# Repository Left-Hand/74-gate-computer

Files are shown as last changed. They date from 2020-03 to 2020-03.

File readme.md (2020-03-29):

# 本文档用于帮助您快速理解本微型计算机的构成
## 特征及功能

* 核心频率期待值为16Mhz，保守预估为8Mhz（暂未测试，待实体机研制出来后测试）
* 绝大多数指令为1T，不使用微指令 *部分另外说明
* 使用冯·诺伊曼架构（最初是使用哈佛架构）
* 使用74门作为本计算机的核心组件，并且不使用其他可编程组件（单片机，FPGA，CPLD等）

* 支持VGA显卡，分辨率为256*240。为4片is62c256分为两组乒乓工作，能够硬件上下回滚，自动修改地址为下一个字符
* 包含2个16位定时器，可屏蔽计时器信号，产生7位权中断
* PC(program counter)程序计数器为24位，能够寻址宽度为2M，前一半分配给AT28系列或是W27C系列芯片作为引导程序，后半部分为单片8Mbit的
sram，用于储存数据和运行程序
* 支持硬件ALU加速乘除操作，需要配置ALU相关寄存器，核心运算部分在16个时钟内完成（不包括配置寄存器及载入读出）

---
## 动机及声明

本人在16年左右看了commdore64的测评，认为非常新奇，于是整天幻想做一个自己的计算机，于17年开始构思（但是当时想的都是一些怪点子，比如用FR储存器作为Vram，使用摇摇棒作为显示屏等），直到下半年到18年出才正式开始用74构造切实可行的电路，并且陆续发布相关文章（黑历史bushi），最后在digital软件下逐步仿真出我想要的电路

主页：https://space.bilibili.com/28690875

专栏：https://www.kechuang.org/t/83193

本项目为开源项目，可能会出相关套件，请勿盗用。
由于我是一名在校高一年级高中生，因学业原因可能进度推展缓慢

---
## 文件

主目录下有一个POB.dig文件，为项目的主文件。使用hneemann的digtial作为仿真的ide（需要安装java），可以在 https://github.com/hneemann/Digital 中找到

作者的提供的库并不适合本项目，我将example/lib下的文件做了替换，解压主目录下的lib.zip文件并替换，方可使用本项目

ES目录下为旧的模块测试用文件，曾有模块化的打算，但是因无法看到底层电路的状态而放弃这一方案

---
## 原理
本计算机与其他微机不同，没有微指，例如C语言中的

```
A = B;
```
在大部分微机中，这条指令包括数个微指令：

```
1. 使B寄存器输出总线使能
2. 控制A载入总线中的数据
3. B寄存器输出结束
4. 检查其他操作...
```

但是，在本机中，绝大多数指令（不涉及修改返回PC值）为1T指令，即一条指令只花费一个周期

此机中，花费两个指令：
```
1. 切换为B寄存器输出到总线
2. 向A寄存器发出载入脉冲
```

再比如一个稍微复杂的（A，B分别为ALU内部的两个寄存器）：

```
C = A + B;
```
执行操作如下（对应一个周期）：

```
1. 切换为立即数寄存器输出到总线
2. 输出加法的ALU控制码（使用74181作为ALU，有多位控制译码线，无法简单操作）
3. ALU载入控制码
4. 切换为ALU输出到总线
5. C寄存器载入总线中的内容
```

故而，在本机中大部分操作使用译码器实现。有两种选通通道，P以及O，均为6位，各自可选通64个不同的脉冲，其区别在于
* P中只会在CLK主时钟发出脉冲时发出脉冲
* O会一直保存为上次载入之后的内容，且持续输出

这样，我们需要操作诸如A = B的操作，先修改O的指针以使B输出，再是P指向A载入的脉冲并放出脉冲，即可完成这样的操作

---
## 指令结构

单个指令为8bit，如果后缀了操作数，那么则为16bit单个操作的字节这样分配

| 7 | 6 | 5 | 4 | 3 | 2 | 1 | 0 |
| -- | -- | -- | -- | -- | -- | -- | -- |
|下一位数据有无| 是否为O指令 | P5/O5 | P4/O4 | P3/O3 | P2/O2 |P1/O1 | P0/O0

需要说明的是，数据必须在指令之前给出，这使我们的汇编码写起来似乎有点反人类，但是这样做也是合情合理的

例如，A寄存器载入的指令为001(前包含一位0表示8进制)
下面是一段实现"A = 0x19"的汇编代码(此处为方便没有配置A寄存器,实际需要):

```
BUSO 0x19
ACP
```

这里我们的BUSO指使总线上的立即数寄存器输出(为000（八进制中的0，八进制不使用如0x，0b的前缀，而是0）)，它的出现同时为了引入0x19这样一个操作数，我们把它编译出来
```
| 1 | 1 | 0 | 0 | 0 | 0 | 0 | 0 | //BUSO指令，下接操作数
| 0 | 0 | 0 | 1 | 0 | 0 | 1 | 1 | //操作数0x19
| 0 | 0 | 0 | 0 | 0 | 0 | 0 | 1 | //A寄存器载入控制符
```
这样，我们的A寄存器就可以载入0x19这样的数字了其背后的逻辑控制稍显复杂，我们不做讨论

---

## 操作符
下面列出所有操作符（空为未定）

P操作符:

|序列号|汇编助记符|说明|
| --- | --- | --- |
|__000000__|NON|不做任何操作|
|000001|ACP|向A寄存器输出脉冲，视当前操作状态而定|
|000010|AMR|A寄存器清零|
|000011|STL|使A寄存器操作状态为左移|
|000100|STR|使A寄存器操作状态为右移|
|000101|LDM|使A寄存器操作状态为载入|
|000110|BLLD|使BL寄存器载入|
|000111|BHLD|使BH寄存器载入|
|__001000__|AILD|使A寄存器右侧移位寄存器载入|
|001001|MLD|使M寄存器载入（硬件乘法加速相关）|
|001010|STC|使ALU进位输入清零|
|001011|CLC|使ALU进位输入制位|
|001100|REC|使ALU进位输入为进位输出|
|001101|NF|第一次移位操作禁止（硬件除法加速相关）|
|001110|CAI|清除A寄存器右移移入数据（硬件乘法加速相关）|
|001111|ACLD|ALU控制符载入|
|__010000__|PCLLD|程序计数器最低字节预载入|
|010001|PCMLD|程序计数器中字节预载入|
|010010|PCHLD|程序计数器高字节预载入|
|010011|FBK|强制备份当前程序计数器至备份0|
|010100|RD|读写储存器操作为读|
|010101|WT|读写储存器操作为写|
|010110|RET|返回备份0的程序地址|
|010111|GED|程序计数器备份至备份1，读写预载入的地址数据并返回|
|__011000__|JMP|无条件跳转预载入的地址|
|011001|HLT|宕机|
|011010|JC|在ALU状态寄存器输出情况下，有进位输出跳转|
|011011|JNC|在ALU状态寄存器输出情况下，无进位输出跳转|
|011100|JZ|在ALU状态寄存器输出情况下，ALU得数为0时跳转|
|011101|JNZ|在ALU状态寄存器输出情况下，ALU得数不为0时跳转|
|011110|JV|在ALU状态寄存器输出情况下，ALU得数溢出跳转|
|011111|JNV|在ALU状态寄存器输出情况下，ALU得数未溢出跳转|
|__100000__|T0LLD|定时器T0低位载入|
|100001|T0HLD|定时器T0高位载入|
|100010|T1LLD|定时器T1低位载入|
|100011|T1HLD|定时器T1高位载入|
|100100|CTC|设置定时器中断许可|
|100101|CTI|设置中断许可|
|100110|INT3|强制中断3|
|100111|INT1|强制中断1|
|__101000__|IO0|IO0载入|
|101001|IO1|IO1载入|
|101010|CLD|C寄存器载入|
|101011|DLD|D寄存器载入|
|101100|IOLD|IO口控制数据流寄存器载入 |
|101101|||
|101110|||
|101111|||
|__110000__|||
|110001|||
|110010|||
|110011|||
|110100|||
|110101|||
|110110|||
|110111|||
|__111000__|SAM|设置A组屏幕输出|
|111001|IVS|切换为另一组屏幕输出|
|111010|WVGA|写VGA数据|
|111011|YP|设置Y偏转|
|111100|LXB|准备载入X地址|
|111101|LX|X地址载入|
|111110|LYB|准备载入Y地址|
|111111|LY|Y地址载入|

O操作符:

|序列号|汇编助记符|说明|
| --- | --- | --- |
|__000000__|BUSO|总线立即数寄存器输出|
|000001|UO|ALU输出|
|000010|DO|除法寄存器输出|
|000011|AOO|A寄存器右侧输出寄存器输出|
|000100|ACO|ALU状态输出|
|000101|PCLO|程序计数器低位预输入输出|
|000110|PCMO|程序计数器中位预输入输出|
|000111|PCHO|程序计数器高位预输入输出|
|__001000__|RDTO|读取的储存器数据输出|
|001001|INTO|中断信号编码输出|
|001010|CRO|C寄存器输出|
|001011|DRO|D寄存器输出|
|001100|IO0O|IO0输出|
|001101|IO1O|IO1输出|

---
## 汇编器及烧录

主目录下的asm.py文件，使用python写了一个简易的汇编器，用于将类似汇编代码更为底层的代码转换为机器码，省去人力编写的痛苦，写完之后将文档（txt格式）的地址修改进python代码中，在命令行的输出中可以找到编译出的机器码，将这段文本修改进入POB.dig文件下（实质上是xml文件），在ROM的data属性中替换为该段文本

---
## 各个寄存器逻辑详解

待补充

---
## 其他

koishi赛高

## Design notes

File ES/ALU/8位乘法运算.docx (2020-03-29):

8位乘法运算

使用8位CPU运行，纯运行16周期，配合16Mhz晶振可以达到1Mhz的运算效率

测试:

145×222=32190（1001 0001×1101 1110=0111 1101 1011 1110）

0000 0000 0111 1110 1110

0000 0000 1001 0001

--------------------- (0) -------------------- (4)

0000 0000 1 0000 1111 1110

0000 0000 0 1000 0111 1111 0

1001 0001 0000 0000

--------------------- (1) -------------------- (5)

1001 0001 0 1000 0111 1111 0

0100 1000 10 0100 0011 1111 10

1001 0001 1001 0001

--------------------- (2) --------------------- (6)

1101 1001 10 1101 0100 1111 10

0110 1100 110 0110 1010 0111 110

1001 0001 1001 0001

--------------------- (3) --------------------- (7)

1111 1101 110 1111 1011 0111 110

0111 1110 1110 0111 1101 1011 1110

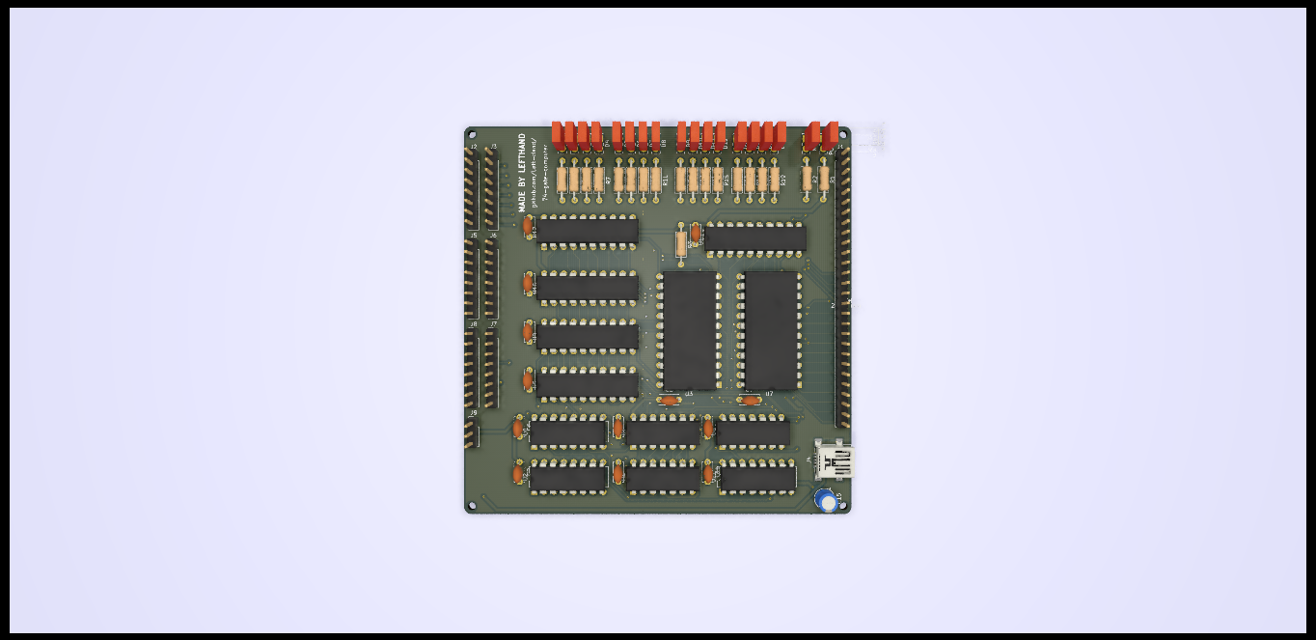
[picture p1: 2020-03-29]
kicad/ALU1/ALU1.png

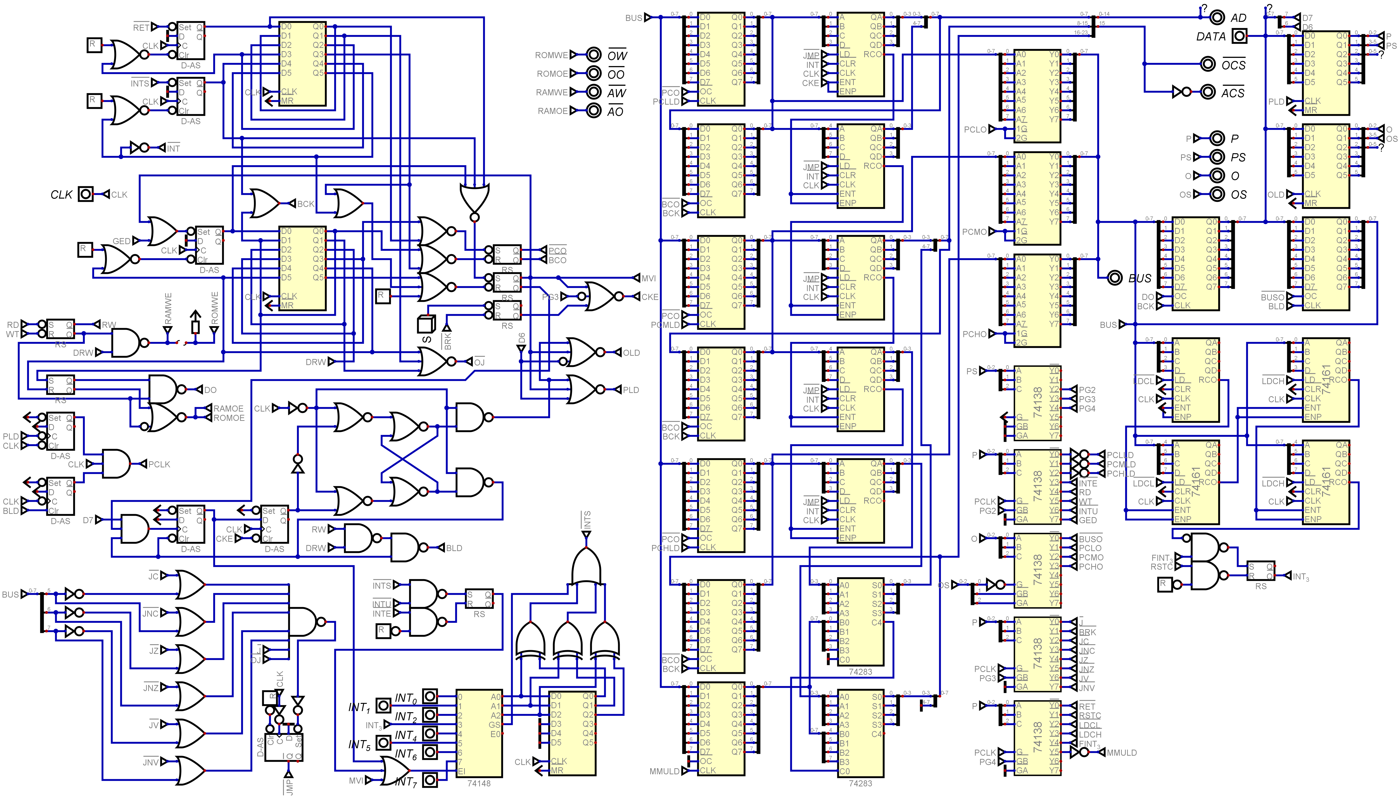
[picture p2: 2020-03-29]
ES/MEM/MEMORY_moudle.png

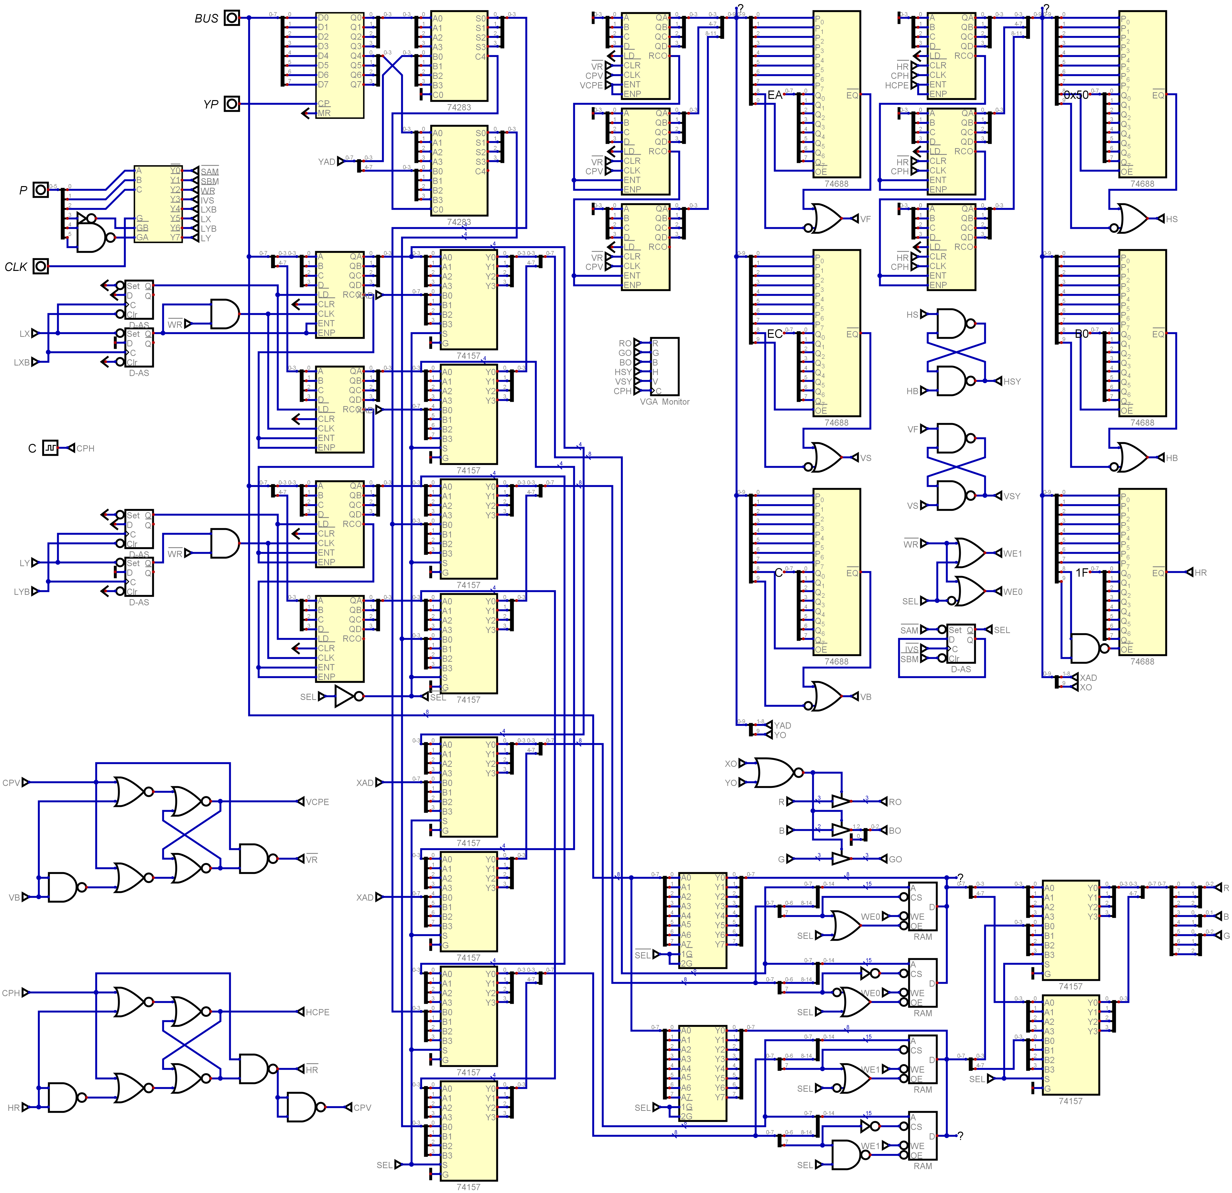
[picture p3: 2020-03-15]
ES/VGA/vga.png

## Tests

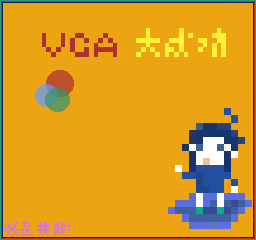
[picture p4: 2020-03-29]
ES/VGA/testimage.png

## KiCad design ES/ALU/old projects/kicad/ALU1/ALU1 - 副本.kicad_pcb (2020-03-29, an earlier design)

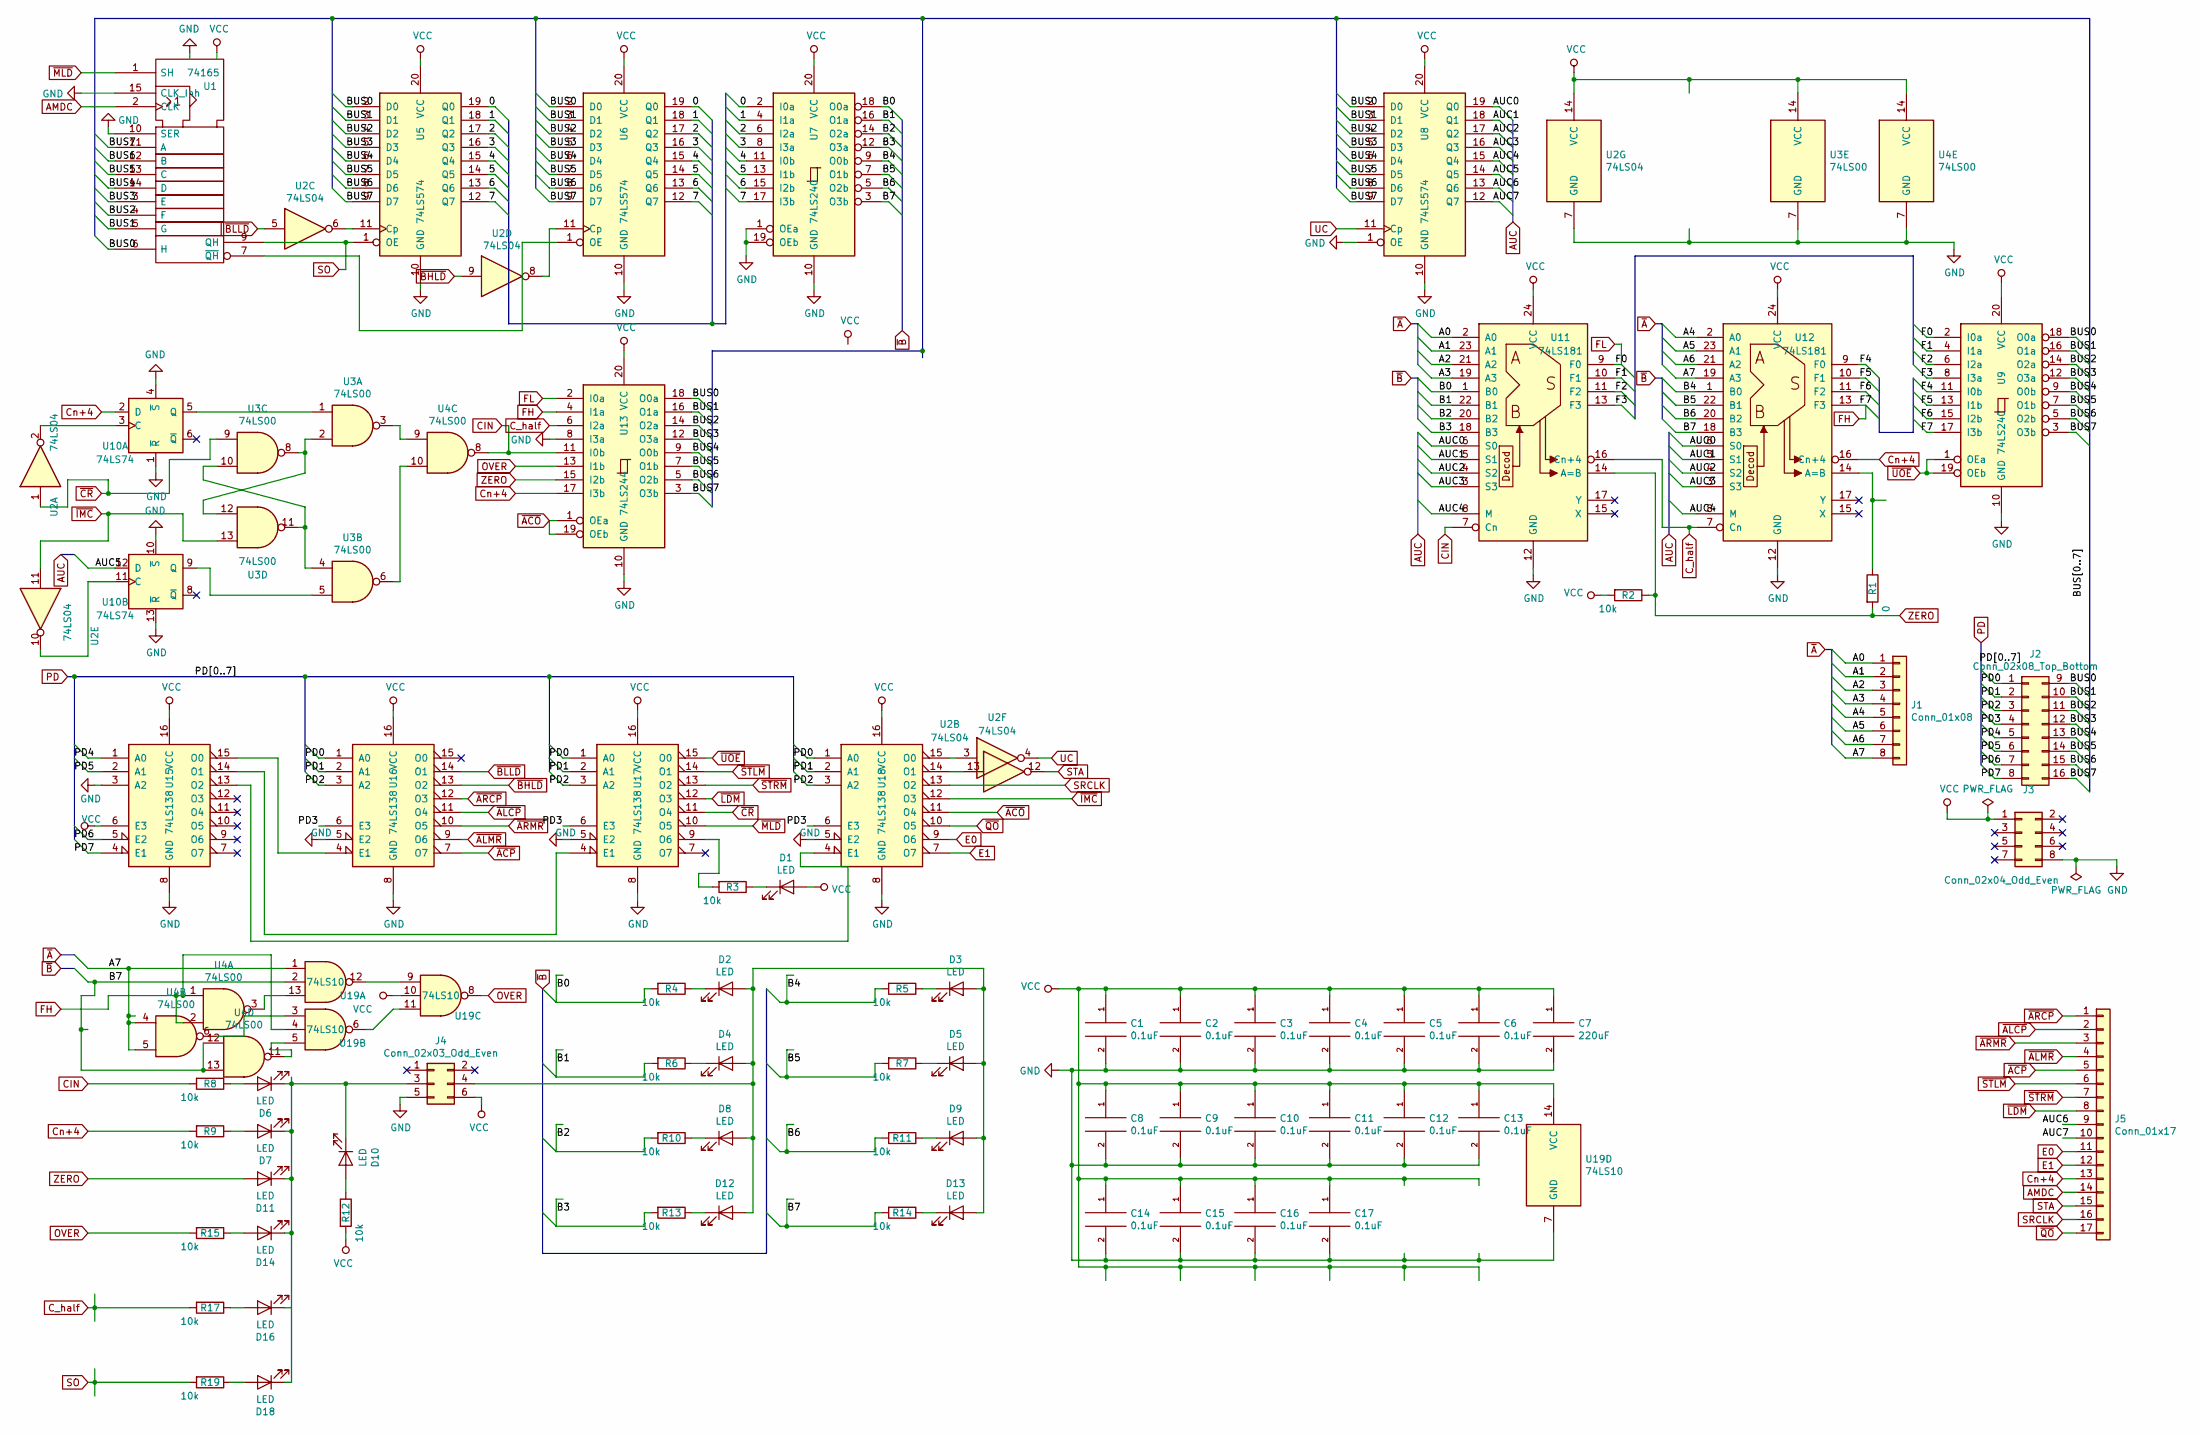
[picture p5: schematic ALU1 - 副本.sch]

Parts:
C1, C2, C3, C4, C5, C6, C8, C9, C10, C11, C12, C13, C14, C15, C16, C17: 0.1uF; C_Disc_D5.0mm_W2.5mm_P5.00mm
C7: 220uF; C_Radial_D6.3mm_H7.0mm_P2.50mm
D1, D2, D3, D4, D5, D6, D7, D8, D9, D10, D11, D12, D13, D14, D16, D18: LED; LED_Rectangular_W5.0mm_H2.0mm
J1: Conn_01x08; PinHeader_1x08_P2.54mm_Vertical
J2: Conn_02x08_Top_Bottom; PinHeader_2x08_P2.54mm_Horizontal
J3: Conn_02x04_Odd_Even; PinHeader_2x04_P2.54mm_Horizontal
J4: Conn_02x03_Odd_Even; PinHeader_2x03_P2.54mm_Vertical
J5: Conn_01x17; PinHeader_1x17_P2.54mm_Vertical
R1: 0; R_0805_2012Metric
R2, R3, R4, R5, R6, R7, R8, R9, R10, R11, R12, R13, R14, R15, R17, R19: 10k; R_0805_2012Metric
U1: 74165; DIP-16_W7.62mm
U2: 74LS04; DIP-14_W7.62mm
U3, U4: 74LS00; DIP-14_W7.62mm
U5, U6, U8: 74LS574; DIP-20_W7.62mm
U7, U9: 74LS240; DIP-20_W7.62mm
U10: 74LS74; DIP-14_W7.62mm
U11, U12: 74LS181; DIP-24_W15.24mm
U13: 74LS244; DIP-20_W7.62mm
U15, U16, U17, U18: 74LS138; DIP-16_W7.62mm
U19: 74LS10; DIP-14_W7.62mm

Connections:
/0: U5.19 (Q0), U6.19 (Q0), U7.2 (I0a)
/1: U5.18 (Q1), U6.18 (Q1), U7.4 (I1a)
/2: U5.17 (Q2), U6.17 (Q2), U7.6 (I2a)
/3: U5.16 (Q3), U6.16 (Q3), U7.8 (I3a)
/4: U5.15 (Q4), U6.15 (Q4), U7.11 (I0b)
/5: U5.14 (Q5), U6.14 (Q5), U7.13 (I1b)
/6: U5.13 (Q6), U6.13 (Q6), U7.15 (I2b)
/7: U5.12 (Q7), U6.12 (Q7), U7.17 (I3b)
/A0: J1.1, U11.2 (A0)
/A1: J1.2, U11.23 (A1)
/A2: J1.3, U11.21 (A2)
/A3: J1.4, U11.19 (A3)
/A4: J1.5, U12.2 (A0)
/A5: J1.6, U12.23 (A1)
/A6: J1.7, U12.21 (A2)
/A7: J1.8, U4.4, U4.5, U12.19 (A3), U19.1
/AUC0: U8.19 (Q0), U11.6 (S0), U12.6 (S0)
/AUC1: U8.18 (Q1), U11.5 (S1), U12.5 (S1)
/AUC2: U8.17 (Q2), U11.4 (S2), U12.4 (S2)
/AUC3: U8.16 (Q3), U11.3 (S3), U12.3 (S3)
/AUC4: U8.15 (Q4), U11.8 (M), U12.8 (M)
/AUC5: U8.14 (Q5), U10.12 (D)
/AUC6: J5.9, U8.13 (Q6)
/AUC7: J5.10, U8.12 (Q7)
/B0: R4.2, U7.18 (O0a), U11.1 (B0)
/B1: R6.2, U7.16 (O1a), U11.22 (B1)
/B2: R10.2, U7.14 (O2a), U11.20 (B2)
/B3: R13.2, U7.12 (O3a), U11.18 (B3)
/B4: R5.2, U7.9 (O0b), U12.1 (B0)
/B5: R7.2, U7.7 (O1b), U12.22 (B1)
/B6: R11.2, U7.5 (O2b), U12.20 (B2)
/B7: R14.2, U4.12, U4.13, U7.3 (O3b), U12.18 (B3), U19.2
/BUS0: J2.9, U1.6 (H), U5.2 (D0), U6.2 (D0), U8.2 (D0), U9.18 (O0a), U13.18 (O0a)
/BUS1: J2.10, U1.5 (G), U5.3 (D1), U6.3 (D1), U8.3 (D1), U9.16 (O1a), U13.16 (O1a)
/BUS2: J2.11, U1.4 (F), U5.4 (D2), U6.4 (D2), U8.4 (D2), U9.14 (O2a), U13.14 (O2a)
/BUS3: J2.12, U1.3 (E), U5.5 (D3), U6.5 (D3), U8.5 (D3), U9.12 (O3a), U13.12 (O3a)
/BUS4: J2.13, U1.14 (D), U5.6 (D4), U6.6 (D4), U8.6 (D4), U9.9 (O0b), U13.9 (O0b)
/BUS5: J2.14, U1.13 (C), U5.7 (D5), U6.7 (D5), U8.7 (D5), U9.7 (O1b), U13.7 (O1b)
/BUS6: J2.15, U1.12 (B), U5.8 (D6), U6.8 (D6), U8.8 (D6), U9.5 (O2b), U13.5 (O2b)
/BUS7: J2.16, U1.11 (A), U5.9 (D7), U6.9 (D7), U8.9 (D7), U9.3 (O3b), U13.3 (O3b)
/F1: U9.4 (I1a), U11.10 (F1)
/F2: U9.6 (I2a), U11.11 (F2)
/F3: U9.8 (I3a), U11.13 (F3)
/F4: U9.11 (I0b), U12.9 (F0)
/F5: U9.13 (I1b), U12.10 (F1)
/F6: U9.15 (I2b), U12.11 (F2)
/PD0: J2.1, U16.1 (A0), U17.1 (A0), U18.1 (A0)
/PD1: J2.2, U16.2 (A1), U17.2 (A1), U18.2 (A1)
/PD2: J2.3, U16.3 (A2), U17.3 (A2), U18.3 (A2)
/PD3: J2.4, U16.6 (E3), U17.6 (E3), U18.6 (E3)
/PD4: J2.5, U15.1 (A0)
/PD5: J2.6, U15.2 (A1)
/PD6: J2.7, U15.5 (E2)
/PD7: J2.8, U15.4 (E1)
AMDC: J5.14, U1.2 (CLK)
CIN: R8.2, U4.8, U11.7 (Cn), U13.11 (I0b)
C_half: R17.2, U11.16 (Cn+4), U12.7 (Cn), U13.6 (I2a)
Cn+4: J5.13, R9.2, U10.2 (D), U12.16 (Cn+4), U13.17 (I3b)
E0: J5.11, U18.9 (O6)
E1: J5.12, U18.7 (O7)
FH: U4.1, U4.2, U9.17 (I3b), U12.13 (F3), U13.4 (I1a), U19.4
FL: U9.2 (I0a), U11.9 (F0), U13.2 (I0a)
GND: C1.2, C2.2, C3.2, C4.2, C5.2, C6.2, C7.2, C8.2, C9.2, C10.2, C11.2, C12.2, C13.2, C14.2, C15.2, C16.2, C17.2, J3.8, J4.5, U1.8 (GND), U1.10 (SER), U1.15 (CLK_Inh), U2.7 (GND), U3.7 (GND), U4.7 (GND), U5.10 (GND), U6.10 (GND), U7.1 (OEa), U7.10 (GND), U7.19 (OEb), U8.1 (OE), U8.10 (GND), U9.10 (GND), U10.1 (~R), U10.4 (~S), U10.10 (~S), U10.13 (~R), U11.12 (GND), U12.12 (GND), U13.8 (I3a), U13.10 (GND), U15.3 (A2), U15.8 (GND), U16.5 (E2), U16.8 (GND), U17.5 (E2), U17.8 (GND), U18.5 (E2), U18.8 (GND), U19.7 (GND); also elsewhere on the board
unnamed: D1.1 (K), R3.1
unnamed: D2.1 (K), R4.1
unnamed: D3.1 (K), R5.1
unnamed: D4.1 (K), R6.1
unnamed: D5.1 (K), R7.1
unnamed: D6.2 (A), R8.1
unnamed: D7.2 (A), R9.1
unnamed: D8.1 (K), R10.1
unnamed: D9.1 (K), R11.1
unnamed: D6.1 (K), D7.1 (K), D10.1 (K), D11.1 (K), D14.1 (K), D16.1 (K), D18.1 (K), J4.3
unnamed: D10.2 (A), R12.1
unnamed: D12.1 (K), R13.1
unnamed: D2.2 (A), D3.2 (A), D4.2 (A), D5.2 (A), D8.2 (A), D9.2 (A), D12.2 (A), D13.2 (A), J4.4
unnamed: D13.1 (K), R14.1
unnamed: D14.2 (A), R15.1
unnamed: D16.2 (A), R17.1
unnamed: D18.2 (A), R19.1
unnamed: R1.1, U12.14 (A=B)
unnamed: R3.2, U17.9 (O6)
unnamed: U1.7 (~QH), U6.1 (OE)
unnamed: U2.6, U5.11 (Cp)
unnamed: U2.8, U6.11 (Cp)
unnamed: U3.3, U4.9
unnamed: U3.6, U4.10
unnamed: U3.4, U3.10, U3.11
unnamed: U3.2, U3.8, U3.12
unnamed: U2.2, U10.3 (C)
unnamed: U3.1, U10.5 (Q)
unnamed: U3.5, U10.9 (Q)
unnamed: U2.10, U10.11 (C)
unnamed: U15.13 (O2), U18.4 (E1)
unnamed: U15.14 (O1), U17.4 (E1)
unnamed: U15.15 (O0), U16.4 (E1)
unnamed: U2.13, U18.14 (O1)
unnamed: U2.3, U18.15 (O0)
unnamed: U4.6, U19.3
unnamed: U4.11, U19.5
unnamed: U19.6, U19.11
unnamed: U19.9, U19.12
unnamed: U4.3, U19.13
OVER: R15.2, U13.13 (I1b), U19.8
SO: R19.2, U1.9 (QH), U5.1 (OE)
SRCLK: J5.16, U18.13 (O2)
STA: J5.15, U2.12
UC: U2.4, U8.11 (Cp)
VCC: C1.1, C2.1, C3.1, C4.1, C5.1, C6.1, C7.1, C8.1, C9.1, C10.1, C11.1, C12.1, C13.1, C14.1, C15.1, C16.1, C17.1, D1.2 (A), J3.1, J4.6, R2.2, R12.2, U1.16 (VCC), U2.14 (VCC), U3.14 (VCC), U4.14 (VCC), U5.20 (VCC), U6.20 (VCC), U7.20 (VCC), U8.20 (VCC), U9.20 (VCC), U11.24 (VCC), U12.24 (VCC), U13.20 (VCC), U15.6 (E3), U15.16 (VCC), U16.16 (VCC), U17.16 (VCC), U18.16 (VCC), U19.10, U19.14 (VCC); also elsewhere on the board
ZERO: D11.2 (A), R1.2, R2.1, U11.14 (A=B), U13.15 (I2b)
~ACO: U13.1 (OEa), U13.19 (OEb), U18.11 (O4)
~ACP: J5.5, U16.7 (O7)
~ALCP: J5.2, U16.11 (O4)
~ALMR: J5.4, U16.9 (O6)
~ARCP: J5.1, U16.12 (O3)
~ARMR: J5.3, U16.10 (O5)
~BHLD: U2.9, U16.13 (O2)
~BLLD: U2.5, U16.14 (O1)
~CR: U2.1, U3.9, U17.11 (O4)
~IMC: U2.11, U3.13, U18.12 (O3)
~LDM: J5.8, U17.12 (O3)
~MLD: U1.1 (SH), U17.10 (O5)
~QO: J5.17, U18.10 (O5)
~STLM: J5.6, U17.14 (O1)
~STRM: J5.7, U17.13 (O2)
~UOE: U9.1 (OEa), U9.19 (OEb), U17.15 (O0)

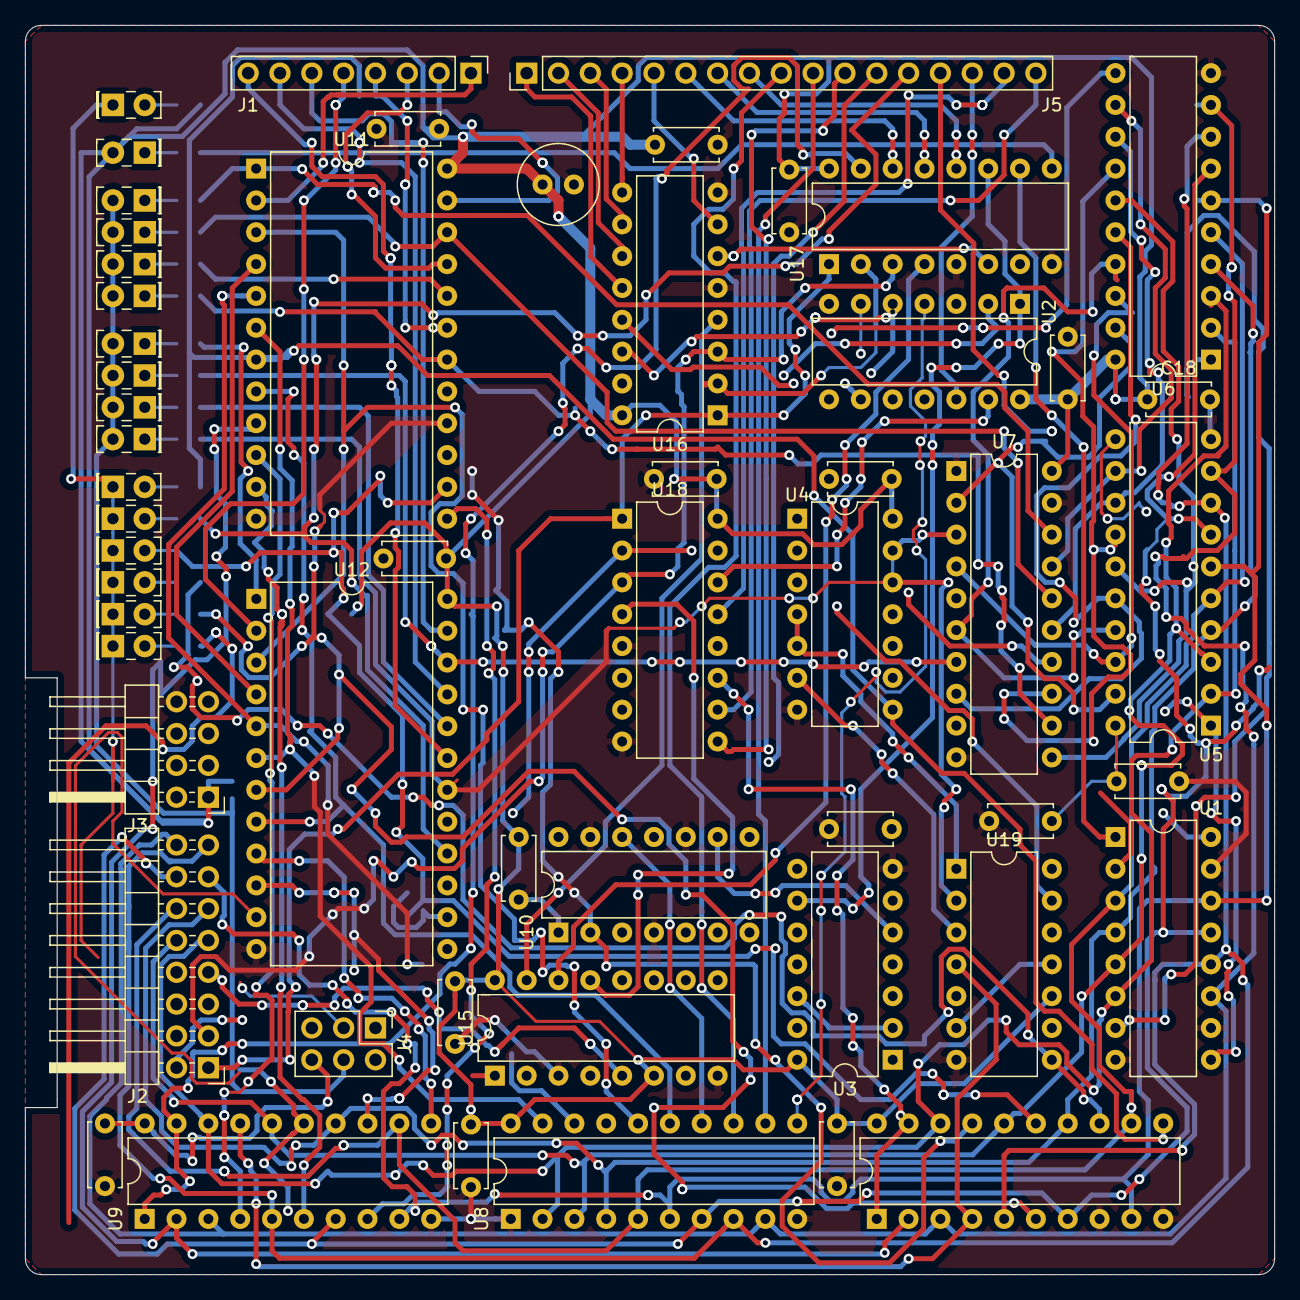
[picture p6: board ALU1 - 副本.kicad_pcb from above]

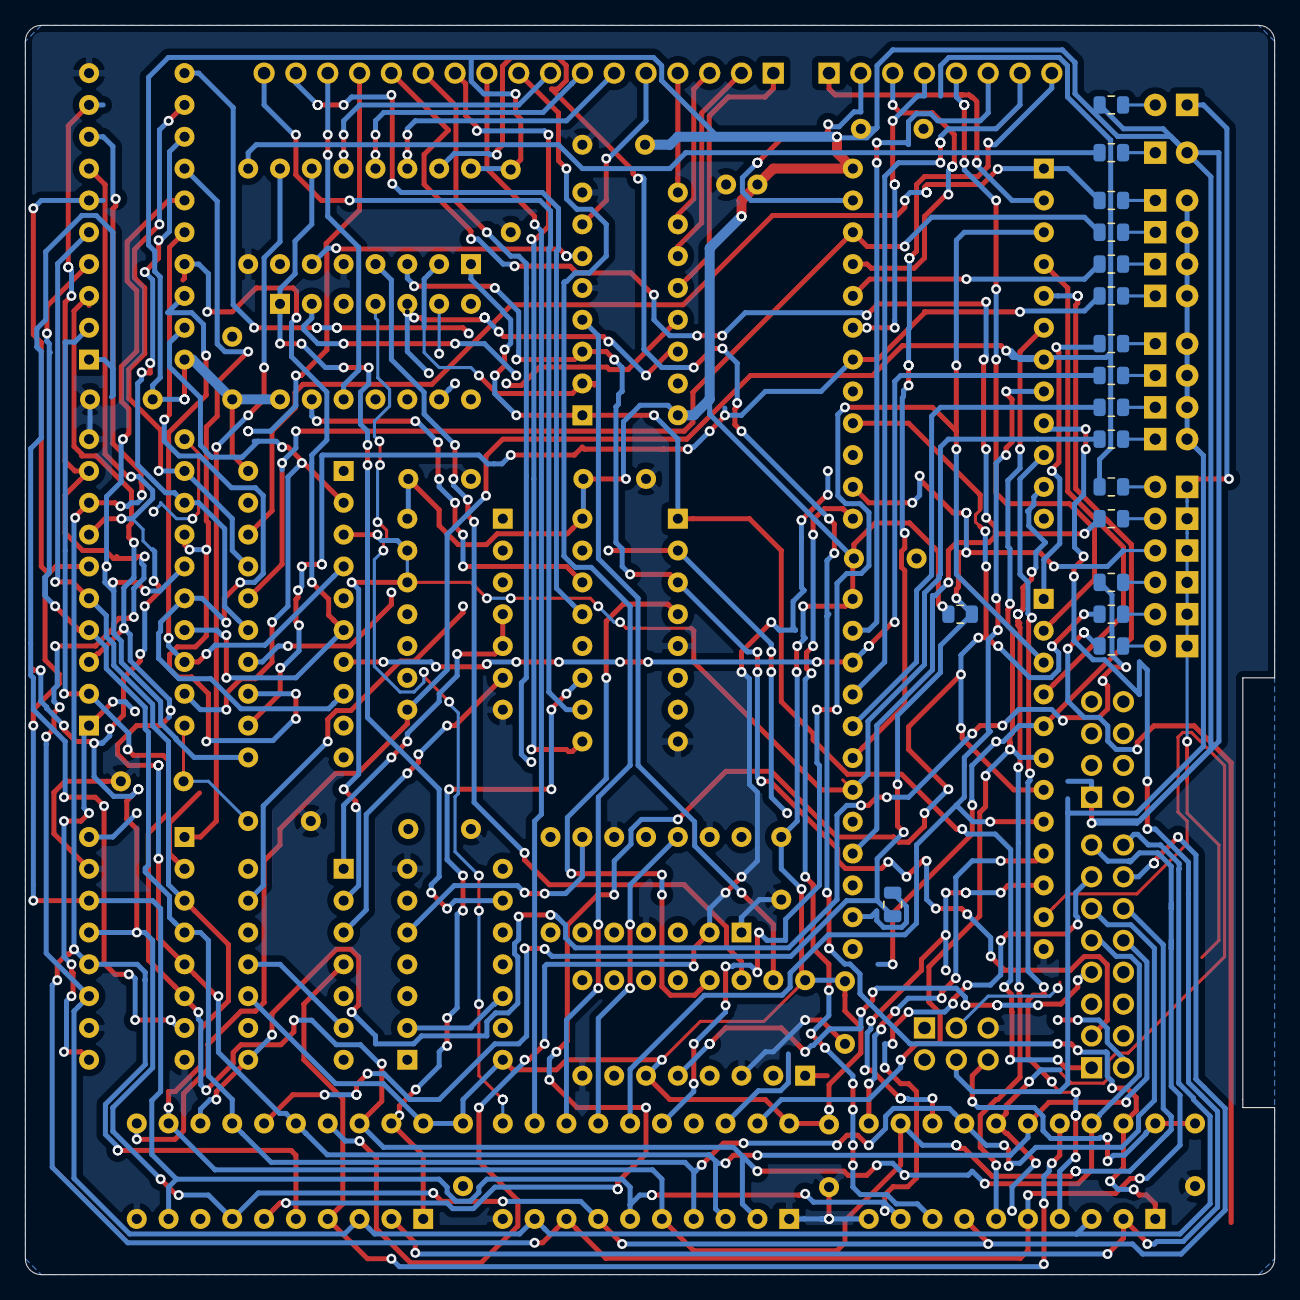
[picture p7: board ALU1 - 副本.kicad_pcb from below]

Board: 2 copper layers, 99.7 x 99.7 mm, 73 parts (17 on the bottom side), 126 nets.

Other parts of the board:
C18: 0.1uF; C_Disc_D5.0mm_W2.5mm_P5.00mm

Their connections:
GND: C18.2; also elsewhere on the board
VCC: C18.1; also elsewhere on the board

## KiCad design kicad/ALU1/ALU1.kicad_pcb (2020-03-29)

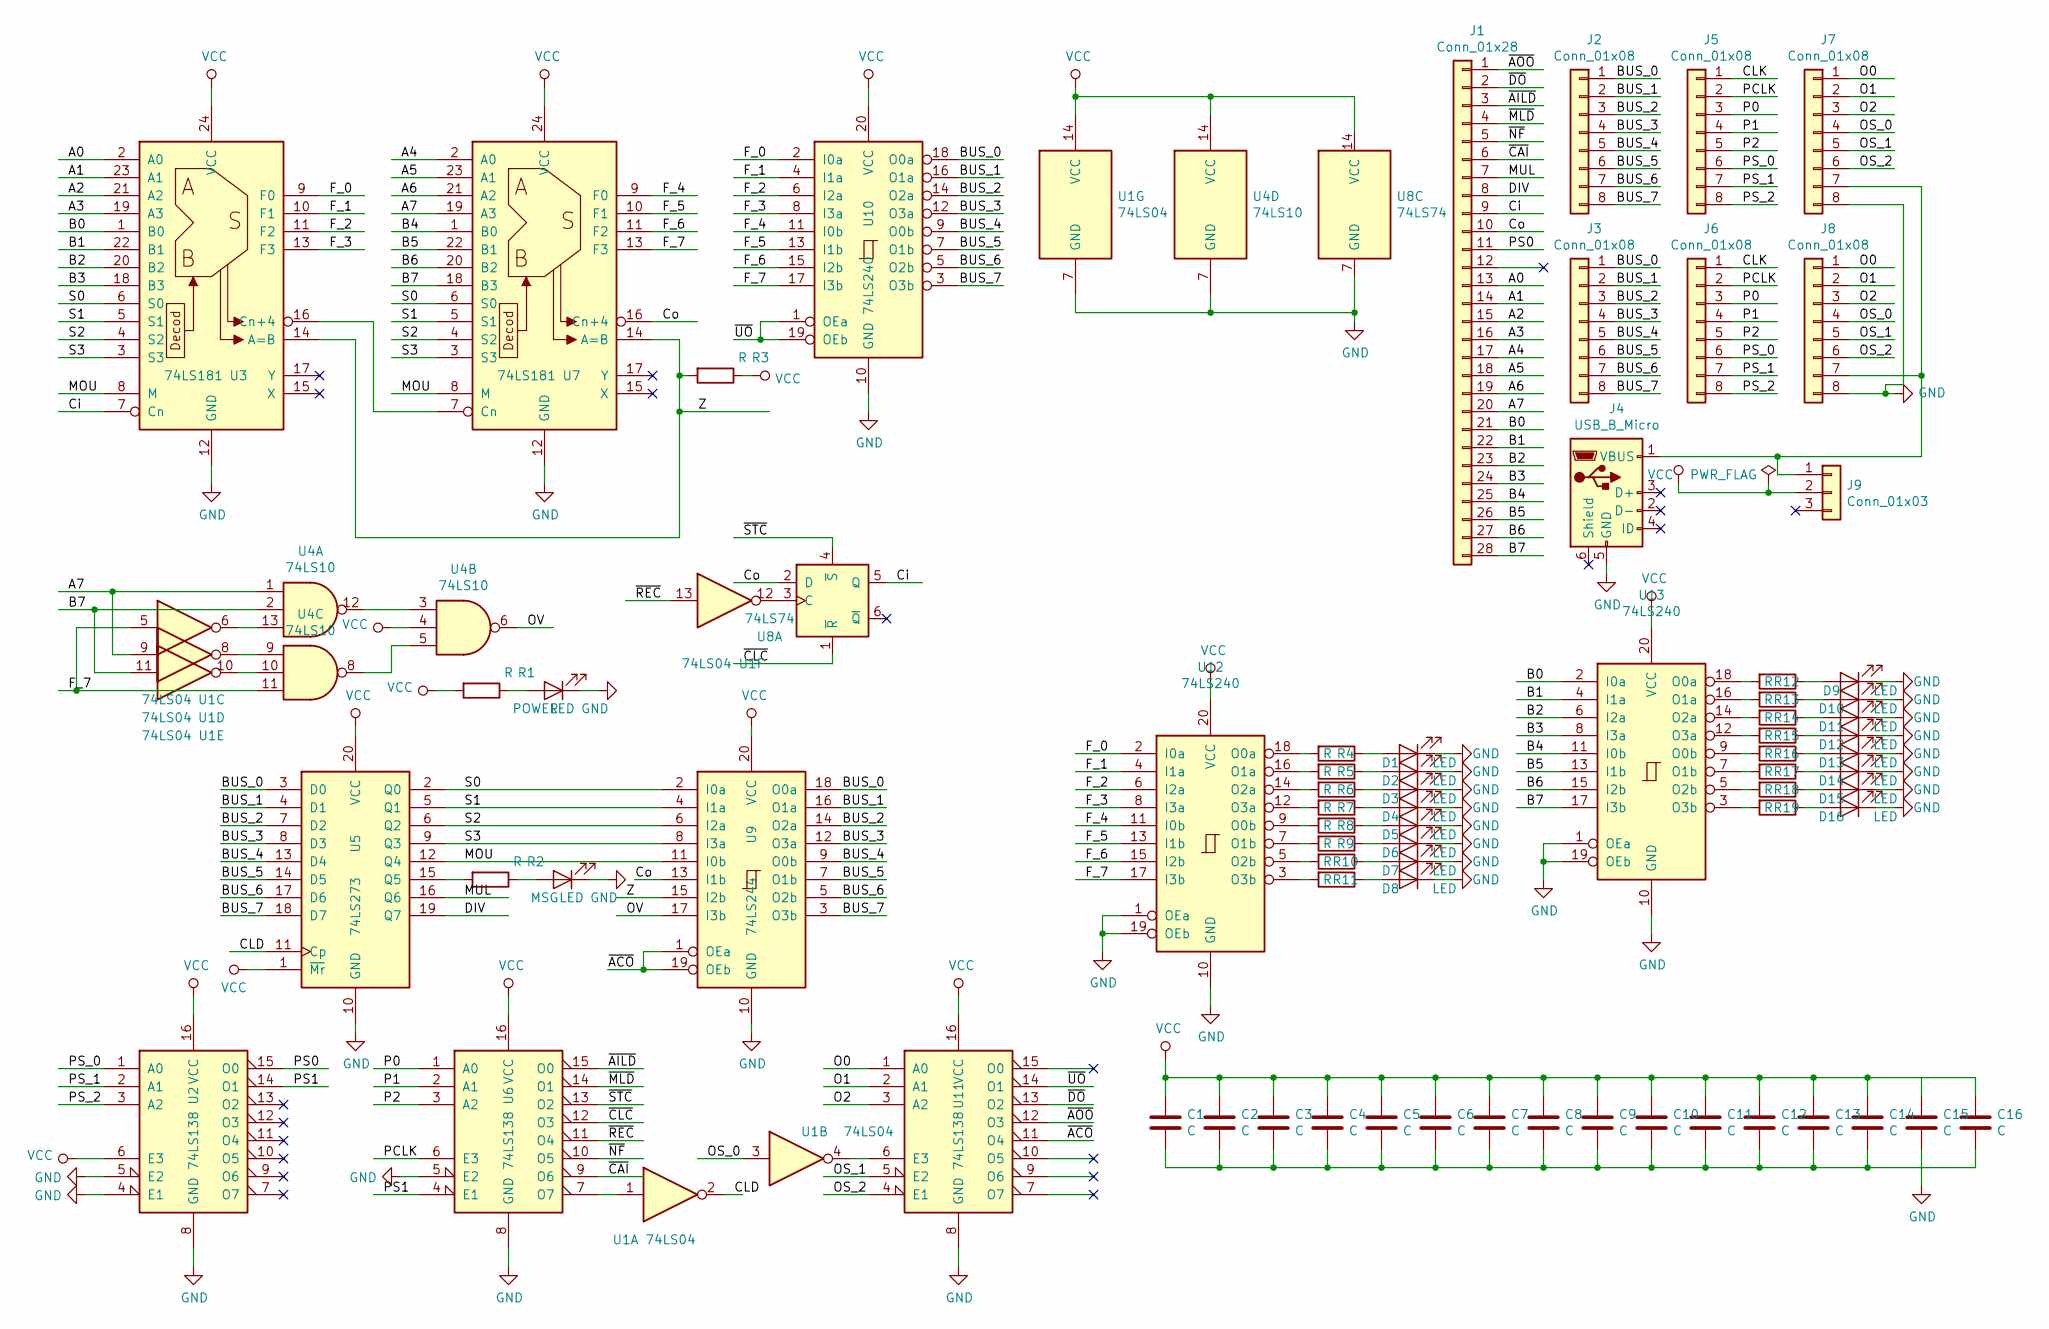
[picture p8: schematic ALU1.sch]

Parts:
C1, C2, C3, C4, C5, C6, C7, C8, C9, C10, C11, C12, C13, C14: C; C_Disc_D5.0mm_W2.5mm_P5.00mm
C15: C; CP_Radial_D5.0mm_P2.00mm
C16: C
D1, D2, D3, D4, D5, D6, D7, D8, D9, D10, D11, D12, D13, D14, D15, D16: LED; LED_Rectangular_W5.0mm_H2.0mm
J1: Conn_01x28; PinHeader_1x28_P2.54mm_Vertical
J2, J3, J5, J6, J7, J8: Conn_01x08; PinHeader_1x08_P2.54mm_Vertical
J4: USB_B_Micro; USB_Mini-B_Lumberg_2486_01_Horizontal
J9: Conn_01x03; PinHeader_1x03_P2.54mm_Vertical
MSG: LED; LED_Rectangular_W5.0mm_H2.0mm
POWER: LED; LED_Rectangular_W5.0mm_H2.0mm
R1, R2, R3, R4, R5, R6, R7, R8, R9, R10, R11, R12, R13, R14, R15, R16, R17, R18, R19: R; R_Axial_DIN0207_L6.3mm_D2.5mm_P10.16mm_Horizontal
U1: 74LS04; DIP-14_W7.62mm
U2, U6, U11: 74LS138; DIP-16_W7.62mm
U3, U7: 74LS181; DIP-24_W15.24mm
U4: 74LS10; DIP-14_W7.62mm
U5: 74LS273; DIP-20_W7.62mm
U8: 74LS74; DIP-14_W7.62mm
U9: 74LS244; DIP-20_W7.62mm
U10, U12, U13: 74LS240; DIP-20_W7.62mm

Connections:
/A0: J1.13, U3.2 (A0)
/A1: J1.14, U3.23 (A1)
/A2: J1.15, U3.21 (A2)
/A3: J1.16, U3.19 (A3)
/A4: J1.17, U7.2 (A0)
/A5: J1.18, U7.23 (A1)
/A6: J1.19, U7.21 (A2)
/A7: J1.20, U1.9, U4.1, U7.19 (A3)
/B0: J1.21, U3.1 (B0), U13.2 (I0a)
/B1: J1.22, U3.22 (B1), U13.4 (I1a)
/B2: J1.23, U3.20 (B2), U13.6 (I2a)
/B3: J1.24, U3.18 (B3), U13.8 (I3a)
/B4: J1.25, U7.1 (B0), U13.11 (I0b)
/B5: J1.26, U7.22 (B1), U13.13 (I1b)
/B6: J1.27, U7.20 (B2), U13.15 (I2b)
/B7: J1.28, U1.11, U4.2, U7.18 (B3), U13.17 (I3b)
/BUS_0: J2.1, J3.1, U5.3 (D0), U9.18 (O0a), U10.18 (O0a)
/BUS_1: J2.2, J3.2, U5.4 (D1), U9.16 (O1a), U10.16 (O1a)
/BUS_2: J2.3, J3.3, U5.7 (D2), U9.14 (O2a), U10.14 (O2a)
/BUS_3: J2.4, J3.4, U5.8 (D3), U9.12 (O3a), U10.12 (O3a)
/BUS_4: J2.5, J3.5, U5.13 (D4), U9.9 (O0b), U10.9 (O0b)
/BUS_5: J2.6, J3.6, U5.14 (D5), U9.7 (O1b), U10.7 (O1b)
/BUS_6: J2.7, J3.7, U5.17 (D6), U9.5 (O2b), U10.5 (O2b)
/BUS_7: J2.8, J3.8, U5.18 (D7), U9.3 (O3b), U10.3 (O3b)
/CLD: U1.2, U5.11 (Cp)
/CLK: J5.1, J6.1
/Ci: J1.9, U3.7 (Cn), U8.5 (Q)
/Co: J1.10, U7.16 (Cn+4), U8.2 (D), U9.13 (I1b)
/DIV: J1.8, U5.19 (Q7)
/F_0: U3.9 (F0), U10.2 (I0a), U12.2 (I0a)
/F_1: U3.10 (F1), U10.4 (I1a), U12.4 (I1a)
/F_2: U3.11 (F2), U10.6 (I2a), U12.6 (I2a)
/F_3: U3.13 (F3), U10.8 (I3a), U12.8 (I3a)
/F_4: U7.9 (F0), U10.11 (I0b), U12.11 (I0b)
/F_5: U7.10 (F1), U10.13 (I1b), U12.13 (I1b)
/F_6: U7.11 (F2), U10.15 (I2b), U12.15 (I2b)
/F_7: U1.5, U4.11, U7.13 (F3), U10.17 (I3b), U12.17 (I3b)
/MOU: U3.8 (M), U5.12 (Q4), U7.8 (M), U9.11 (I0b)
/MUL: J1.7, U5.16 (Q6)
/O0: J7.1, J8.1, U11.1 (A0)
/O1: J7.2, J8.2, U11.2 (A1)
/O2: J7.3, J8.3, U11.3 (A2)
/OS_0: J7.4, J8.4, U1.3
/OS_1: J7.5, J8.5, U11.5 (E2)
/OS_2: J7.6, J8.6, U11.4 (E1)
/OV: U4.6, U9.17 (I3b)
/P0: J5.3, J6.3, U6.1 (A0)
/P1: J5.4, J6.4, U6.2 (A1)
/P2: J5.5, J6.5, U6.3 (A2)
/PCLK: J5.2, J6.2, U6.6 (E3)
/PS0: J1.11, U2.15 (O0)
/PS1: U2.14 (O1), U6.4 (E1)
/PS_0: J5.6, J6.6, U2.1 (A0)
/PS_1: J5.7, J6.7, U2.2 (A1)
/PS_2: J5.8, J6.8, U2.3 (A2)
/S0: U3.6 (S0), U5.2 (Q0), U7.6 (S0), U9.2 (I0a)
/S1: U3.5 (S1), U5.5 (Q1), U7.5 (S1), U9.4 (I1a)
/S2: U3.4 (S2), U5.6 (Q2), U7.4 (S2), U9.6 (I2a)
/S3: U3.3 (S3), U5.9 (Q3), U7.3 (S3), U9.8 (I3a)
/Z: R3.2, U3.14 (A=B), U7.14 (A=B), U9.15 (I2b)
/~ACO: U9.1 (OEa), U9.19 (OEb), U11.11 (O4)
/~AILD: J1.3, U6.15 (O0)
/~AOO: J1.1, U11.12 (O3)
/~CAI: J1.6, U6.9 (O6)
/~CLC: U6.12 (O3), U8.1 (~R)
/~DO: J1.2, U11.13 (O2)
/~MLD: J1.4, U6.14 (O1)
/~NF: J1.5, U6.10 (O5)
/~REC: U1.13, U6.11 (O4)
/~STC: U6.13 (O2), U8.4 (~S)
/~UO: U10.1 (OEa), U10.19 (OEb), U11.14 (O1)
GND: C1.2, C2.2, C3.2, C4.2, C5.2, C6.2, C7.2, C8.2, C9.2, C10.2, C11.2, C12.2, C13.2, C14.2, C15.2, C16.2, D1.1 (K), D2.1 (K), D3.1 (K), D4.1 (K), D5.1 (K), D6.1 (K), D7.1 (K), D8.1 (K), D9.1 (K), D10.1 (K), D11.1 (K), D12.1 (K), D13.1 (K), D14.1 (K), D15.1 (K), D16.1 (K), J4.5 (GND), J7.8, J8.8, MSG.1 (K), POWER.1 (K), U1.7 (GND), U2.4 (E1), U2.5 (E2), U2.8 (GND), U3.12 (GND), U4.7 (GND), U5.10 (GND), U6.5 (E2), U6.8 (GND), U7.12 (GND), U8.7 (GND), U9.10 (GND), U10.10 (GND), U11.8 (GND), U12.1 (OEa), U12.10 (GND), U12.19 (OEb), U13.1 (OEa), U13.10 (GND), U13.19 (OEb)
unnamed: D1.2 (A), R4.1
unnamed: D2.2 (A), R5.1
unnamed: D3.2 (A), R6.1
unnamed: D4.2 (A), R7.1
unnamed: D5.2 (A), R8.1
unnamed: D6.2 (A), R9.1
unnamed: D7.2 (A), R10.1
unnamed: D8.2 (A), R11.1
unnamed: D9.2 (A), R12.1
unnamed: D10.2 (A), R13.1
unnamed: D11.2 (A), R14.1
unnamed: D12.2 (A), R15.1
unnamed: D13.2 (A), R16.1
unnamed: D14.2 (A), R17.1
unnamed: D15.2 (A), R18.1
unnamed: D16.2 (A), R19.1
unnamed: J4.1 (VBUS), J7.7, J8.7, J9.1
unnamed: MSG.2 (A), R2.1
unnamed: POWER.2 (A), R1.1
unnamed: R2.2, U5.15 (Q5)
unnamed: R4.2, U12.18 (O0a)
unnamed: R5.2, U12.16 (O1a)
unnamed: R6.2, U12.14 (O2a)
unnamed: R7.2, U12.12 (O3a)
unnamed: R8.2, U12.9 (O0b)
unnamed: R9.2, U12.7 (O1b)
unnamed: R10.2, U12.5 (O2b)
unnamed: R11.2, U12.3 (O3b)
unnamed: R12.2, U13.18 (O0a)
unnamed: R13.2, U13.16 (O1a)
unnamed: R14.2, U13.14 (O2a)
unnamed: R15.2, U13.12 (O3a)
unnamed: R16.2, U13.9 (O0b)
unnamed: R17.2, U13.7 (O1b)
unnamed: R18.2, U13.5 (O2b)
unnamed: R19.2, U13.3 (O3b)
unnamed: U1.1, U6.7 (O7)
unnamed: U1.4, U11.6 (E3)
unnamed: U1.6, U4.13
unnamed: U1.8, U4.9
unnamed: U1.10, U4.10
unnamed: U1.12, U8.3 (C)
unnamed: U3.16 (Cn+4), U7.7 (Cn)
unnamed: U4.5, U4.8
unnamed: U4.3, U4.12
VCC: C1.1, C2.1, C3.1, C4.1, C5.1, C6.1, C7.1, C8.1, C9.1, C10.1, C11.1, C12.1, C13.1, C14.1, C15.1, C16.1, J9.2, R1.2, R3.1, U1.14 (VCC), U2.6 (E3), U2.16 (VCC), U3.24 (VCC), U4.4, U4.14 (VCC), U5.1 (~Mr), U5.20 (VCC), U6.16 (VCC), U7.24 (VCC), U8.14 (VCC), U9.20 (VCC), U10.20 (VCC), U11.16 (VCC), U12.20 (VCC), U13.20 (VCC)

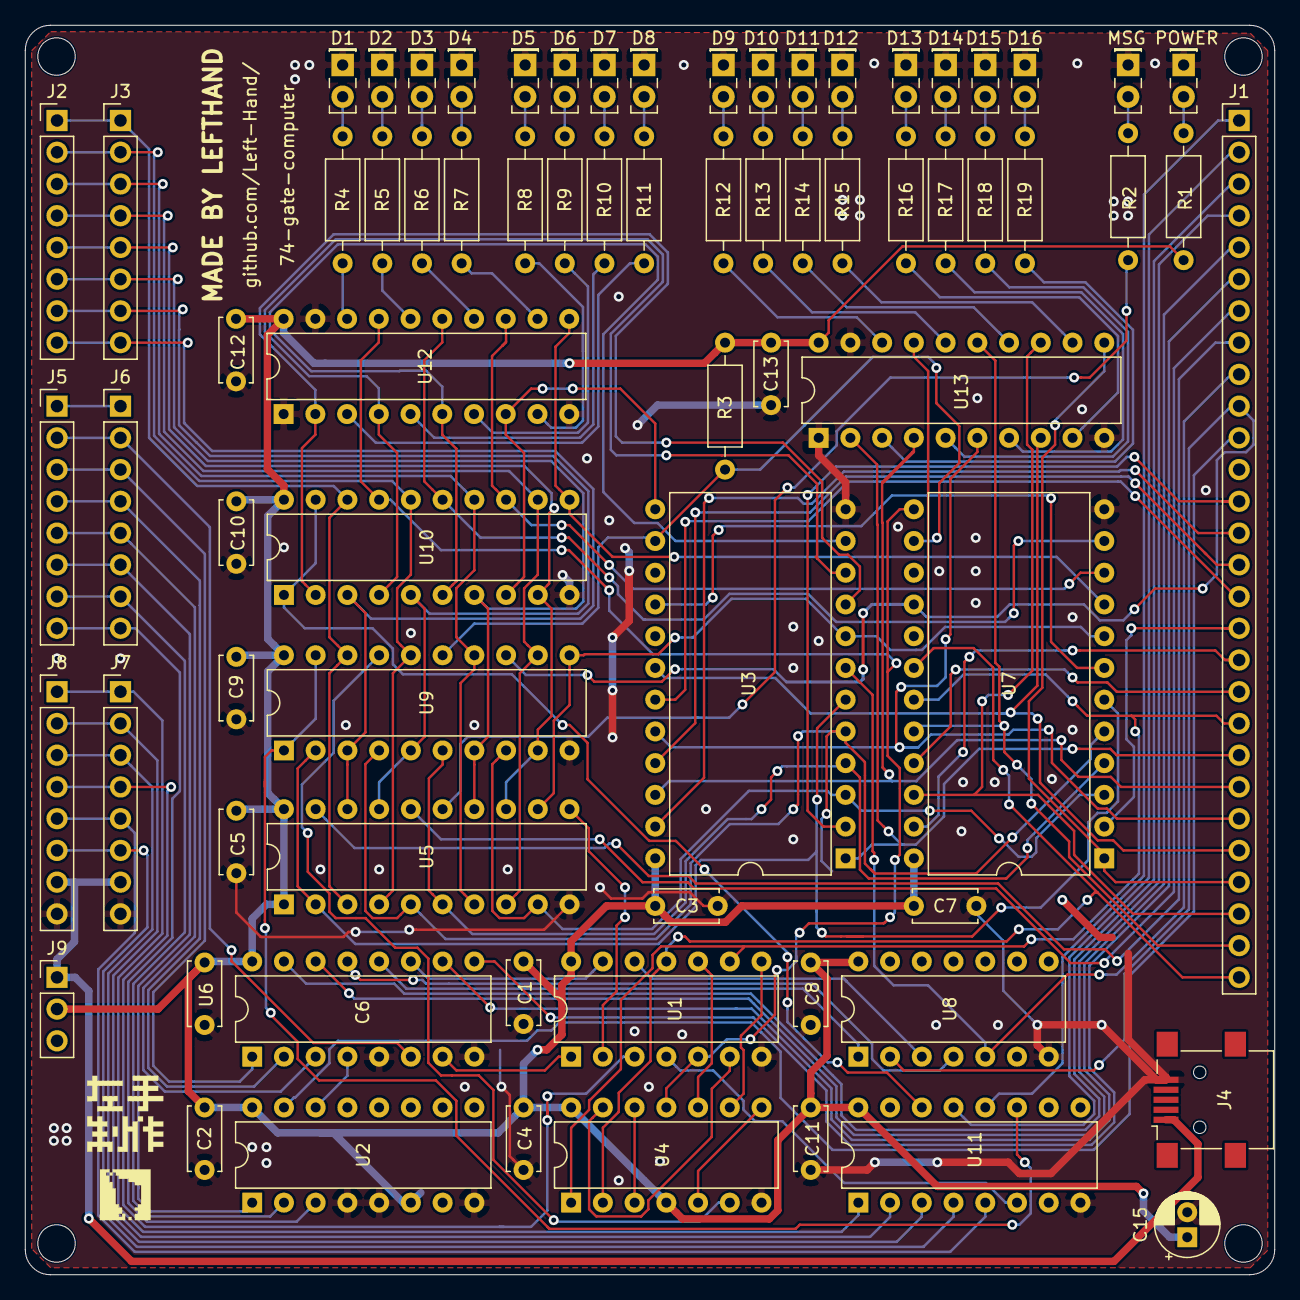
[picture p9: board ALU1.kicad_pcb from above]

Board: 2 copper layers, 100.0 x 100.0 mm, 73 parts (0 on the bottom side), 118 nets.

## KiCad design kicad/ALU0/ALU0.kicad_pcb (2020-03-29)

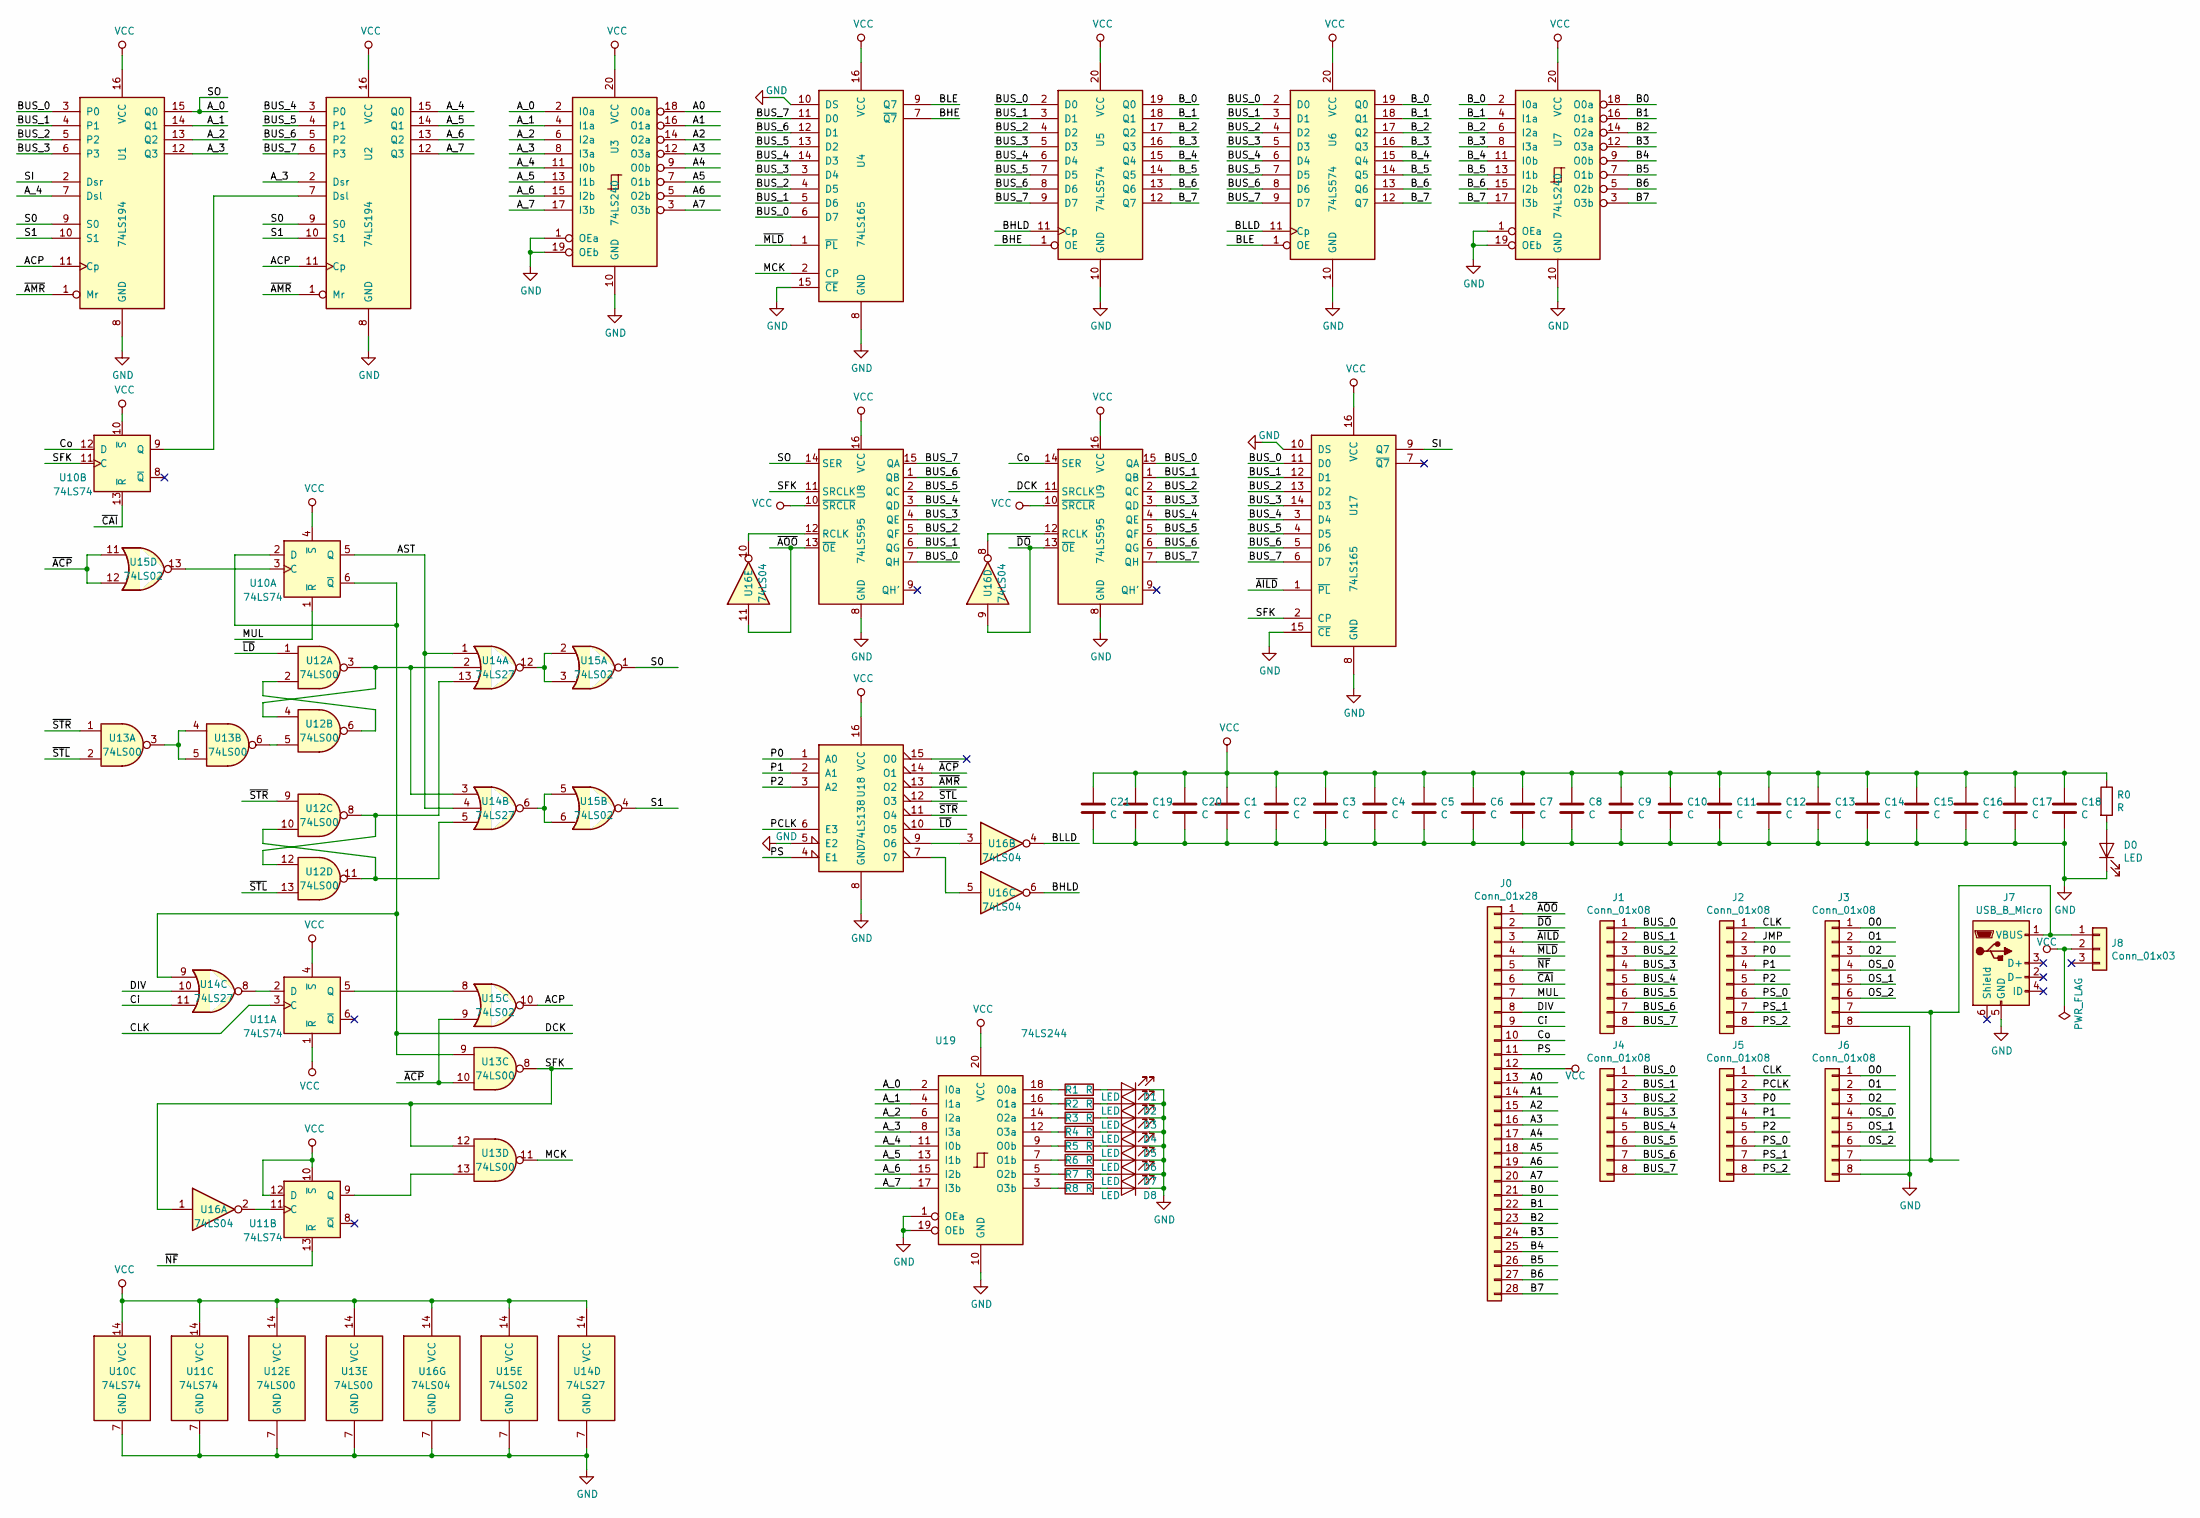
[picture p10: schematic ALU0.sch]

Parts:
C1, C2, C3, C4, C5, C6, C7, C8, C9, C10, C11, C12, C13, C14, C15, C16, C17, C18, C19, C20: C; C_Disc_D5.0mm_W2.5mm_P5.00mm
C21: C; CP_Radial_D5.0mm_P2.00mm
D0, D1, D2, D3, D4, D5, D6, D7, D8: LED; LED_Rectangular_W5.0mm_H2.0mm
J0: Conn_01x28; PinHeader_1x28_P2.54mm_Vertical
J1, J2, J3, J4, J5, J6: Conn_01x08; PinHeader_1x08_P2.54mm_Vertical
J7: USB_B_Micro; USB_Mini-B_Lumberg_2486_01_Horizontal
J8: Conn_01x03; PinHeader_1x03_P2.54mm_Vertical
R0, R1, R2, R3, R4, R5, R6, R7, R8: R; R_Axial_DIN0207_L6.3mm_D2.5mm_P10.16mm_Horizontal
U1, U2: 74LS194; DIP-16_W7.62mm
U3, U7: 74LS240; DIP-20_W7.62mm
U4, U17: 74LS165; DIP-16_W7.62mm
U5, U6: 74LS574; DIP-20_W7.62mm
U8, U9: 74LS595; DIP-16_W7.62mm
U10, U11: 74LS74; DIP-14_W7.62mm
U12, U13: 74LS00; DIP-14_W7.62mm
U14: 74LS27; DIP-14_W7.62mm
U15: 74LS02; DIP-14_W7.62mm
U16: 74LS04; DIP-14_W7.62mm
U18: 74LS138; DIP-16_W7.62mm
U19: 74LS244; DIP-20_W7.62mm

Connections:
/A0: J0.13, U3.18 (O0a)
/A1: J0.14, U3.16 (O1a)
/A2: J0.15, U3.14 (O2a)
/A3: J0.16, U3.12 (O3a)
/A4: J0.17, U3.9 (O0b)
/A5: J0.18, U3.7 (O1b)
/A6: J0.19, U3.5 (O2b)
/A7: J0.20, U3.3 (O3b)
/ACP: U1.11 (Cp), U2.11 (Cp), U15.10
/AST: U10.5 (Q), U14.1, U14.4
/A_0: U1.15 (Q0), U3.2 (I0a), U8.14 (SER), U19.2 (I0a)
/A_1: U1.14 (Q1), U3.4 (I1a), U19.4 (I1a)
/A_2: U1.13 (Q2), U3.6 (I2a), U19.6 (I2a)
/A_3: U1.12 (Q3), U2.2 (Dsr), U3.8 (I3a), U19.8 (I3a)
/A_4: U1.7 (Dsl), U2.15 (Q0), U3.11 (I0b), U19.11 (I0b)
/A_5: U2.14 (Q1), U3.13 (I1b), U19.13 (I1b)
/A_6: U2.13 (Q2), U3.15 (I2b), U19.15 (I2b)
/A_7: U2.12 (Q3), U3.17 (I3b), U19.17 (I3b)
/B0: J0.21, U7.18 (O0a)
/B1: J0.22, U7.16 (O1a)
/B2: J0.23, U7.14 (O2a)
/B3: J0.24, U7.12 (O3a)
/B4: J0.25, U7.9 (O0b)
/B5: J0.26, U7.7 (O1b)
/B6: J0.27, U7.5 (O2b)
/B7: J0.28, U7.3 (O3b)
/BHE: U4.7 (~Q7), U5.1 (OE)
/BHLD: U5.11 (Cp), U16.6
/BLE: U4.9 (Q7), U6.1 (OE)
/BLLD: U6.11 (Cp), U16.4
/BUS_0: J1.1, J4.1, U1.3 (P0), U4.6 (D7), U5.2 (D0), U6.2 (D0), U8.7 (QH), U9.15 (QA), U17.11 (D0)
/BUS_1: J1.2, J4.2, U1.4 (P1), U4.5 (D6), U5.3 (D1), U6.3 (D1), U8.6 (QG), U9.1 (QB), U17.12 (D1)
/BUS_2: J1.3, J4.3, U1.5 (P2), U4.4 (D5), U5.4 (D2), U6.4 (D2), U8.5 (QF), U9.2 (QC), U17.13 (D2)
/BUS_3: J1.4, J4.4, U1.6 (P3), U4.3 (D4), U5.5 (D3), U6.5 (D3), U8.4 (QE), U9.3 (QD), U17.14 (D3)
/BUS_4: J1.5, J4.5, U2.3 (P0), U4.14 (D3), U5.6 (D4), U6.6 (D4), U8.3 (QD), U9.4 (QE), U17.3 (D4)
/BUS_5: J1.6, J4.6, U2.4 (P1), U4.13 (D2), U5.7 (D5), U6.7 (D5), U8.2 (QC), U9.5 (QF), U17.4 (D5)
/BUS_6: J1.7, J4.7, U2.5 (P2), U4.12 (D1), U5.8 (D6), U6.8 (D6), U8.1 (QB), U9.6 (QG), U17.5 (D6)
/BUS_7: J1.8, J4.8, U2.6 (P3), U4.11 (D0), U5.9 (D7), U6.9 (D7), U8.15 (QA), U9.7 (QH), U17.6 (D7)
/B_0: U5.19 (Q0), U6.19 (Q0), U7.2 (I0a)
/B_1: U5.18 (Q1), U6.18 (Q1), U7.4 (I1a)
/B_2: U5.17 (Q2), U6.17 (Q2), U7.6 (I2a)
/B_3: U5.16 (Q3), U6.16 (Q3), U7.8 (I3a)
/B_4: U5.15 (Q4), U6.15 (Q4), U7.11 (I0b)
/B_5: U5.14 (Q5), U6.14 (Q5), U7.13 (I1b)
/B_6: U5.13 (Q6), U6.13 (Q6), U7.15 (I2b)
/B_7: U5.12 (Q7), U6.12 (Q7), U7.17 (I3b)
/CLK: J2.1, J5.1, U11.3 (C)
/Ci: J0.9, U14.11
/Co: J0.10, U9.14 (SER), U10.12 (D)
/DCK: U9.11 (SRCLK), U10.2 (D), U10.6 (~Q), U13.9, U14.9
/DIV: J0.8, U14.10
/MCK: U4.2 (CP), U13.11
/MUL: J0.7, U10.1 (~R)
/O0: J3.1, J6.1
/O1: J3.2, J6.2
/O2: J3.3, J6.3
/OS_0: J3.4, J6.4
/OS_1: J3.5, J6.5
/OS_2: J3.6, J6.6
/P0: J2.3, J5.3, U18.1 (A0)
/P1: J2.4, J5.4, U18.2 (A1)
/P2: J2.5, J5.5, U18.3 (A2)
/PS: J0.11, U18.4 (E1)
/PS_0: J2.6, J5.6
/PS_1: J2.7, J5.7
/PS_2: J2.8, J5.8
/S0: U1.9 (S0), U2.9 (S0), U15.1
/S1: U1.10 (S1), U2.10 (S1), U15.4
/SFK: U8.11 (SRCLK), U10.11 (C), U13.8, U13.12, U16.1, U17.2 (CP)
/SI: U1.2 (Dsr), U17.9 (Q7)
/~ACP: U13.10, U15.9, U15.11, U15.12, U18.14 (O1)
/~AILD: J0.3, U17.1 (~PL)
/~AMR: U1.1 (Mr), U2.1 (Mr), U18.13 (O2)
/~AOO: J0.1, U8.13 (~OE), U16.11
/~CAI: J0.6, U10.13 (~R)
/~DO: J0.2, U9.13 (~OE), U16.9
/~LD: U12.1, U18.10 (O5)
/~MLD: J0.4, U4.1 (~PL)
/~NF: J0.5, U11.13 (~R)
/~STL: U12.13, U13.2, U18.12 (O3)
/~STR: U12.9, U13.1, U18.11 (O4)
GND: C1.1, C2.1, C3.1, C4.1, C5.1, C6.1, C7.1, C8.1, C9.1, C10.1, C11.1, C12.1, C13.1, C14.1, C15.1, C16.1, C17.1, C18.1, C19.1, C20.1, C21.1, D0.1 (K), D1.1 (K), D2.1 (K), D3.1 (K), D4.1 (K), D5.1 (K), D6.1 (K), D7.1 (K), D8.1 (K), J3.8, J6.8, J7.5 (GND), U1.8 (GND), U2.8 (GND), U3.1 (OEa), U3.10 (GND), U3.19 (OEb), U4.8 (GND), U4.10 (DS), U4.15 (~CE), U5.10 (GND), U6.10 (GND), U7.1 (OEa), U7.10 (GND), U7.19 (OEb), U8.8 (GND), U9.8 (GND), U10.7 (GND), U11.7 (GND), U12.7 (GND), U13.7 (GND), U14.7 (GND), U15.7 (GND), U16.7 (GND), U17.8 (GND), U17.10 (DS), U17.15 (~CE), U18.5 (E2), U18.8 (GND), U19.1 (OEa), U19.10 (GND), U19.19 (OEb)
unnamed: D0.2 (A), R0.2
unnamed: D1.2 (A), R1.2
unnamed: D2.2 (A), R2.2
unnamed: D3.2 (A), R3.2
unnamed: D4.2 (A), R4.2
unnamed: D5.2 (A), R5.2
unnamed: D6.2 (A), R6.2
unnamed: D7.2 (A), R7.2
unnamed: D8.2 (A), R8.2
unnamed: J3.7, J6.7, J7.1 (VBUS), J8.1
unnamed: R1.1, U19.18 (O0a)
unnamed: R2.1, U19.16 (O1a)
unnamed: R3.1, U19.14 (O2a)
unnamed: R4.1, U19.12 (O3a)
unnamed: R5.1, U19.9 (O0b)
unnamed: R6.1, U19.7 (O1b)
unnamed: R7.1, U19.5 (O2b)
unnamed: R8.1, U19.3 (O3b)
unnamed: U10.3 (C), U15.13
unnamed: U2.7 (Dsl), U10.9 (Q)
unnamed: U11.2 (D), U14.8
unnamed: U11.5 (Q), U15.8
unnamed: U11.9 (Q), U13.13
unnamed: U11.11 (C), U16.2
unnamed: U12.2, U12.6
unnamed: U12.3, U12.4, U14.2, U14.3
unnamed: U12.5, U13.6
unnamed: U12.10, U12.11, U14.5
unnamed: U12.8, U12.12, U14.13
unnamed: U13.3, U13.4, U13.5
unnamed: U14.6, U15.5, U15.6
unnamed: U14.12, U15.2, U15.3
unnamed: U16.3, U18.9 (O6)
unnamed: U16.5, U18.7 (O7)
unnamed: U9.12 (RCLK), U16.8
unnamed: U8.12 (RCLK), U16.10
VCC: C1.2, C2.2, C3.2, C4.2, C5.2, C6.2, C7.2, C8.2, C9.2, C10.2, C11.2, C12.2, C13.2, C14.2, C15.2, C16.2, C17.2, C18.2, C19.2, C20.2, C21.2, J0.12, J8.2, R0.1, U1.16 (VCC), U2.16 (VCC), U3.20 (VCC), U4.16 (VCC), U5.20 (VCC), U6.20 (VCC), U7.20 (VCC), U8.10 (~SRCLR), U8.16 (VCC), U9.10 (~SRCLR), U9.16 (VCC), U10.4 (~S), U10.10 (~S), U10.14 (VCC), U11.1 (~R), U11.4 (~S), U11.10 (~S), U11.12 (D), U11.14 (VCC), U12.14 (VCC), U13.14 (VCC), U14.14 (VCC), U15.14 (VCC), U16.14 (VCC), U17.16 (VCC), U18.16 (VCC), U19.20 (VCC)

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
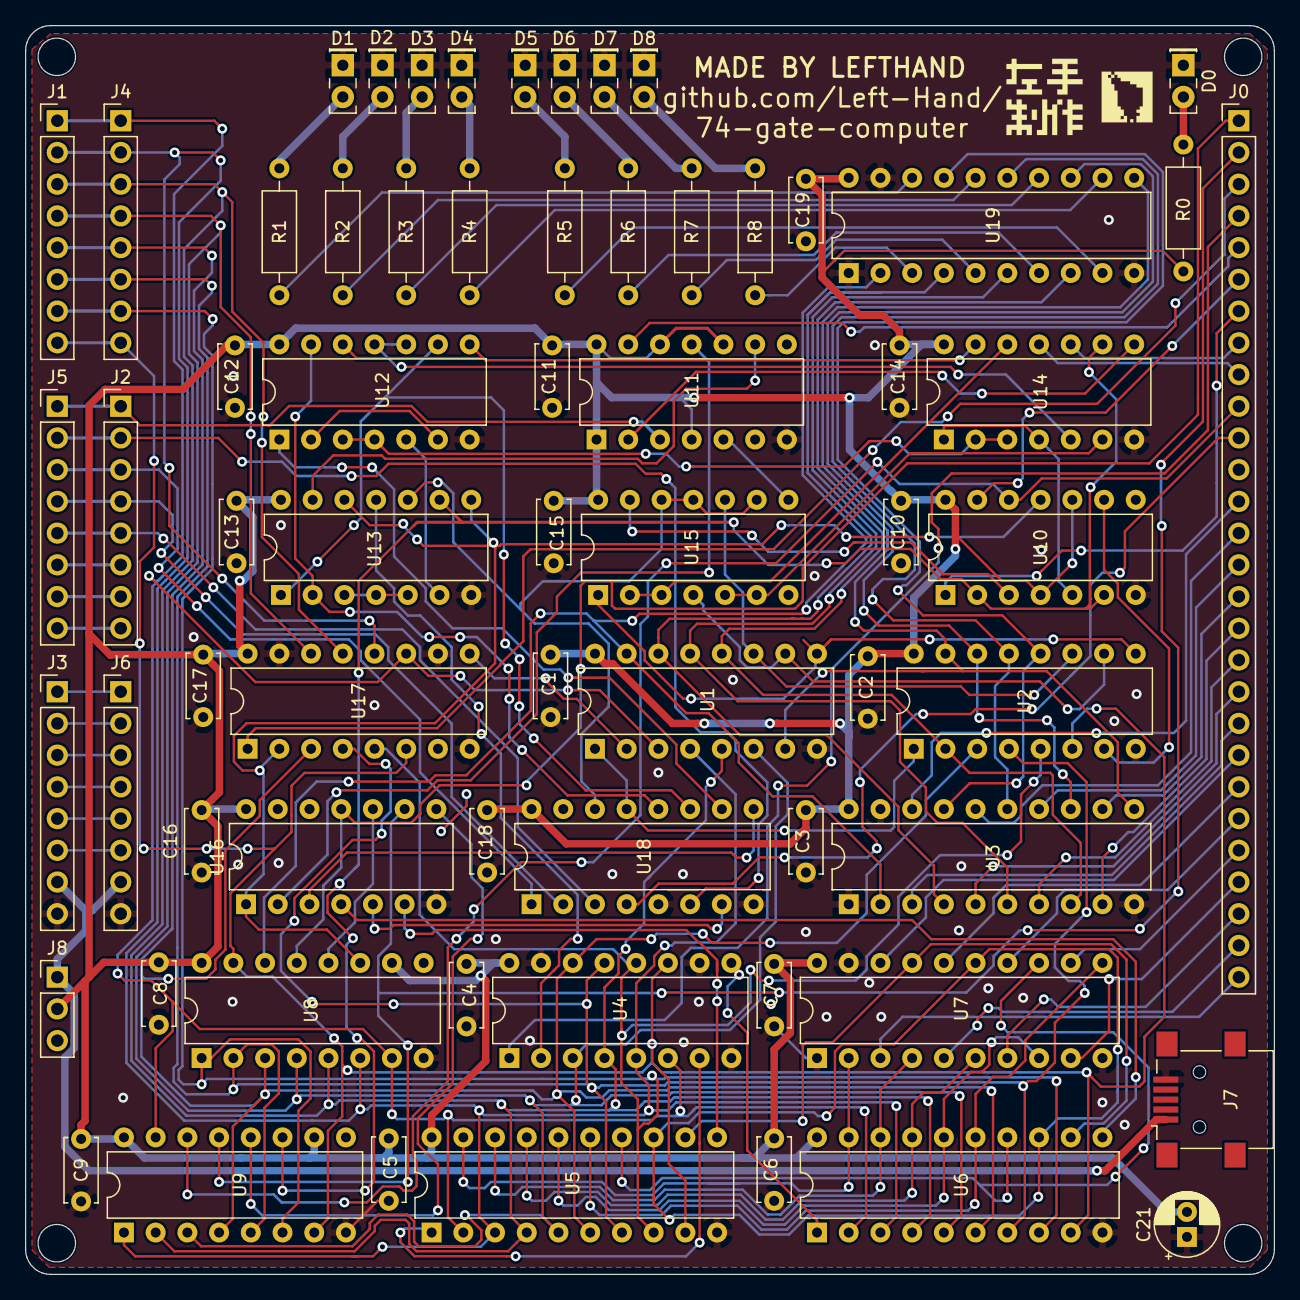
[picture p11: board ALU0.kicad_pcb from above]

Board: 2 copper layers, 100.0 x 100.0 mm, 66 parts (0 on the bottom side), 120 nets.

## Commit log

2020-02-24 Add files via upload
    新增ALU的电路图以及PCB
2020-02-24 Add files via upload
    DIGITAL 文件，用于仿真
2020-03-29 Add files via upload
    更新了所有文件
2020-03-29 Create kicad
2020-03-29 Update: first working version
    [ALU0.kicad_pcb, ALU0.sch, ALU1 - 副本.kicad_pcb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]
